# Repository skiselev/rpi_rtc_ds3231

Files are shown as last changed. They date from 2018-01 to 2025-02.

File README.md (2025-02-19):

# RPi DS3231 RTC
Maxim DS3231 Based RTC Module for Raspberry Pi

## Introduction
This is a real-time clock (RTC) module for Raspberry Pi and Raspberry Pi Zero. The module is similar to [Adafruit PiRTC](https://www.adafruit.com/product/3386), but uses the highly accurate [Maxim Integrated DS3231](https://www.adafruit.com/product/3386) RTC IC with an integrated temperature-compensated crystal oscillator, and more common CR2032 battery.

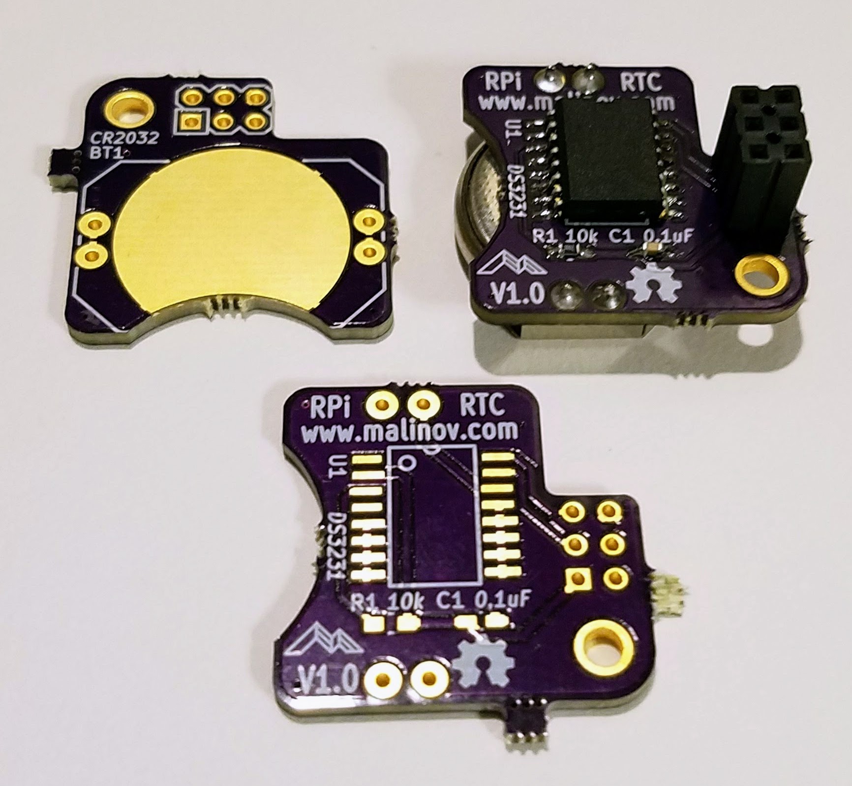
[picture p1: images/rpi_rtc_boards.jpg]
RPi RTC Assembled Board and PCBs


## Hardware Documentation

### Schematic and PCB Layout

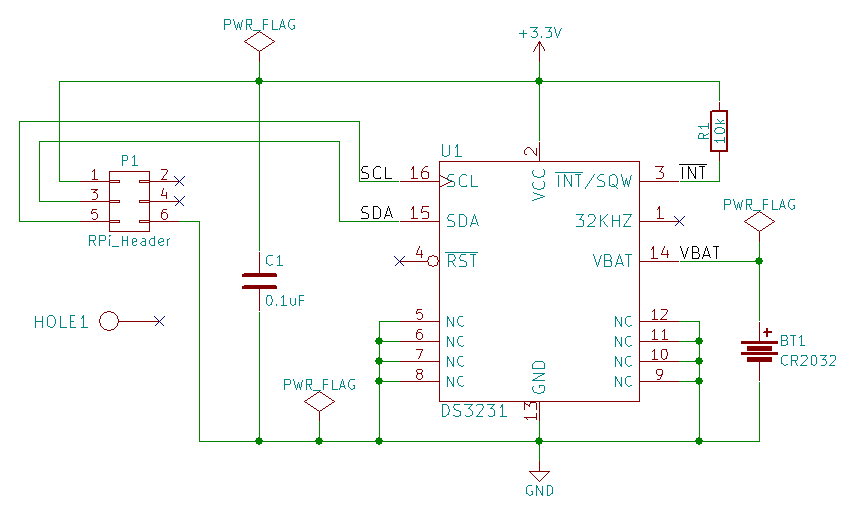
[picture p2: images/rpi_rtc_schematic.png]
RPi RTC Schematic


### Bill of Materials

[RPi DS3231 RTC project on Mouser.com](https://www.mouser.com/ProjectManager/ProjectDetail.aspx?AccessID=eede7ef873) - View and order all components except of the PCB.

[RPi DS3231 RTC on OSH Park](https://oshpark.com/shared_projects/tu7lVnCo) - View and order the PCB.

Component type     | Reference | Description                       | Quantity | Possible sources and notes 
------------------ | --------- | --------------------------------- | -------- | --------------------------
PCB                |           | RPi DS3231 RTC PCB - Version 1.0  | 1        | Order from [OSH Park](https://oshpark.com/shared_projects/tu7lVnCo)
Integrated Circuit | U1        | Maxim DS3231                      | 1        | Mouser [700-DS3231S#T&R-](https://www.mouser.com/ProductDetail/700-DS3231S%23TR-)
Capactior          | C1        | 0.1uF, 0603                       | 6        | Mouser [77-VJ0603Y104JXJPBC](https://www.mouser.com/ProductDetail/77-VJ0603Y104JXJPBC)
Resistor           | R1        | 10 kohm, 0603                     | 1        | Mouser [71-CRCW060310K0FKEB](https://www.mouser.com/ProductDetail/71-CRCW060310K0FKEB)
Connector          | P1        | 3x2, 2.54 mm, socket              | 1        | Mouser [517-929852-01-03-RA](https://www.mouser.com/ProductDetail/517-929852-01-03-RA)
Battery Holder     | BT1       | CR2032 Battery Holder             | 1        | Mouser [712-BAT-HLD-001-THM](https://www.mouser.com/ProductDetail/712-BAT-HLD-001-THM)
Battery            | BT1       | CR2032                            | 1        | Mouser [658-CR2032](https://www.mouser.com/ProductDetail/658-CR2032)

## Software Documentation

### Raspbian Configuration

The following steps assume that you have a fairly new Rapbian distribution installed and running on your Rapsberry Pi, and that RPi DS3231 RTC module is plugged into the Raspberry Pi.

#### Enable I2C Support

Run `raspi-config`:

    $ sudo raspi-config
    
Navigate to the *Interfacing Options* menu. If this menu is missing (on older Raspbian versions), try the *Advanced Options* menu instead.
Next, select the *I2C* menu, and answer *Yes* to *Would you like the ARM I2C interface to be enabled?* and *Would you like the I2C kernel modules to be loaded by default?* questions.

Reboot the system

#### Verify that RTC Module Is Detected

Install `i2c-tools` package:

    $ sudo apt-get install i2c-tools

Run `i2cdetect -y 1` command and verify that the I2C device is detected at address 0x68:

    $ sudo i2cdetect -y 1
         0  1  2  3  4  5  6  7  8  9  a  b  c  d  e  f
    00:          -- -- -- -- -- -- -- -- -- -- -- -- --
    10: -- -- -- -- -- -- -- -- -- -- -- -- -- -- -- --
    20: -- -- -- -- -- -- -- -- -- -- -- -- -- -- -- --
    30: -- -- -- -- -- -- -- -- -- -- -- -- -- -- -- --
    40: -- -- -- -- -- -- -- -- -- -- -- -- -- -- -- --
    50: -- -- -- -- -- -- -- -- -- -- -- -- -- -- -- --
    60: -- -- -- -- -- -- -- -- 68 -- -- -- -- -- -- --
    70: -- -- -- -- -- -- -- --

#### Enable Kernel Support for DS3231 RTC

Open `/boot/firmware/config.txt` in your favorite editor (nano, vi) as root. For example:

    $ sudo nano /boot/firmware/config.txt

Add the following lines at the end of the file:

    # Enable DS3231 RTC
    dtoverlay=i2c-rtc,ds3231

Remove `fake-hwclock` package:

    $ sudo apt-get -y remove fake-hwclock
    $ sudo update-rc.d -f fake-hwclock remove

Enable setting up system time to the RTC time at boot. Open `/lib/udev/hwclock-set` in your favorite editor:

    $ sudo nano /lib/udev/hwclock-set

And comment out the following lines:

    #if [ -e /run/systemd/system ] ; then
    # exit 0
    #fi

Also comment the following line(s):

    #/sbin/hwclock --rtc=$dev --systz --badyear
    #/sbin/hwclock --rtc=$dev --systz

Save the file, and reboot the system

#### Setting and Reading the RTC time from Command Line

* Use `hwclock -w` command to set the RTC time to the system time. You can use `date` command to set and verify the system time prior to writing it to the RTC.
* Use `hwclock --set --date=<date_string>` command to set the RTC time to the time given by <date_string>
* Use `hwclock -r` command to read the time from the RTC

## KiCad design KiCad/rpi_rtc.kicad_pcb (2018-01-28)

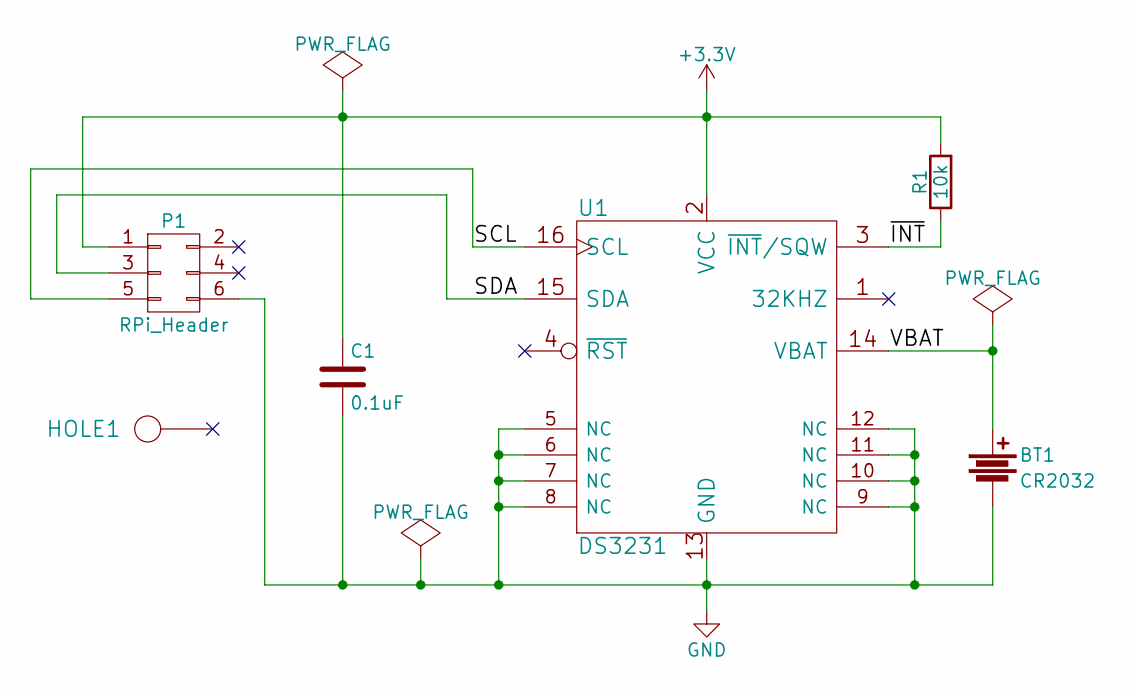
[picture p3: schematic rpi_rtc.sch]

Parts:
BT1: CR2032; Battery_Holder_CR2032_THM
C1: 0.1uF; C_0603_HandSoldering
HOLE1: HOLE; Hole_2.75mm
P1: RPi_Header; Conn_Pin_Header_2x3_2.54mm
R1: 10k; R_0603_HandSoldering
U1: DS3231; IC_SOIC16_Wide

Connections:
+3V3: C1.1, P1.1, R1.2, U1.2 (VCC)
/SCL: P1.5, U1.16 (SCL)
/SDA: P1.3, U1.15 (SDA)
/VBAT: BT1.1, U1.14 (VBAT)
/~INT: R1.1, U1.3 (~INT~/SQW)
GND: BT1.2, C1.2, P1.6, U1.5 (NC), U1.6 (NC), U1.7 (NC), U1.8 (NC), U1.9 (NC), U1.10 (NC), U1.11 (NC), U1.12 (NC), U1.13 (GND)

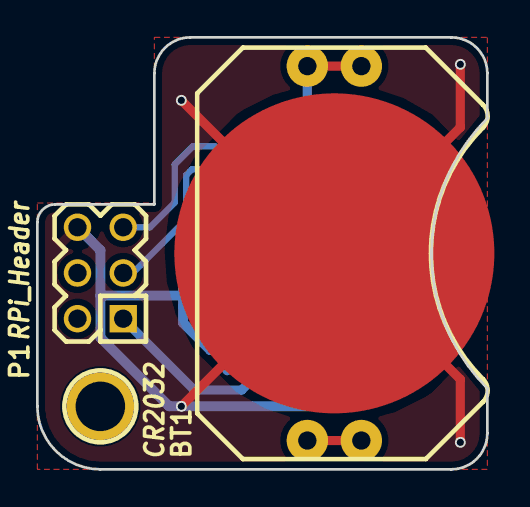
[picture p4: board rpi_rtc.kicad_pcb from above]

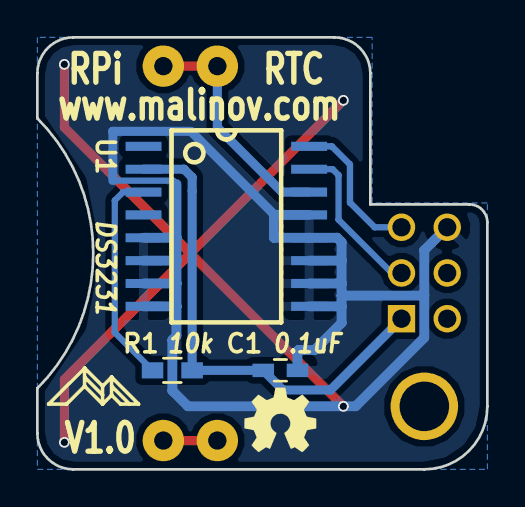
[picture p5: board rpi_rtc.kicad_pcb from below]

Board: 2 copper layers, 25.0 x 24.0 mm, 6 parts (3 on the bottom side), 6 nets.

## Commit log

2018-01-28 KiCad: Schematic and PCB, initial commit
    [rpi_rtc.kicad_pcb, rpi_rtc.sch]
2018-01-28 KiCad: move files to the KiCad directory
    [rpi_rtc.kicad_pcb, rpi_rtc.sch]
2018-01-28 Documentation: Add photo, schematic, and datasheet
